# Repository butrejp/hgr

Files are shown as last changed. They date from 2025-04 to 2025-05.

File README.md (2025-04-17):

this is mostly just the kalico config for my 3d printer, eventually including some custom 3d printed parts I've designed for it and some miscellaneous files related to it.  it's mostly here as a backup, but someone may find it useful.

the mainboard is a BTT Octopus Pro v1.1, it uses an nf-crazy volcano uuhf hotend, CPAP fan, 2gt belts on 20t gears, 4mm pitch ball screws for Z, a euclid probe, and mechanical endstops on x and y.  it's a cartesian bed dropper, similar to an ender 5 kinematically

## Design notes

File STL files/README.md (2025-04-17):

the duct is a janky temporary thing, don't use it unless you have to.  I'm working on something more permanent but it's going slow because temporary fixes are forever

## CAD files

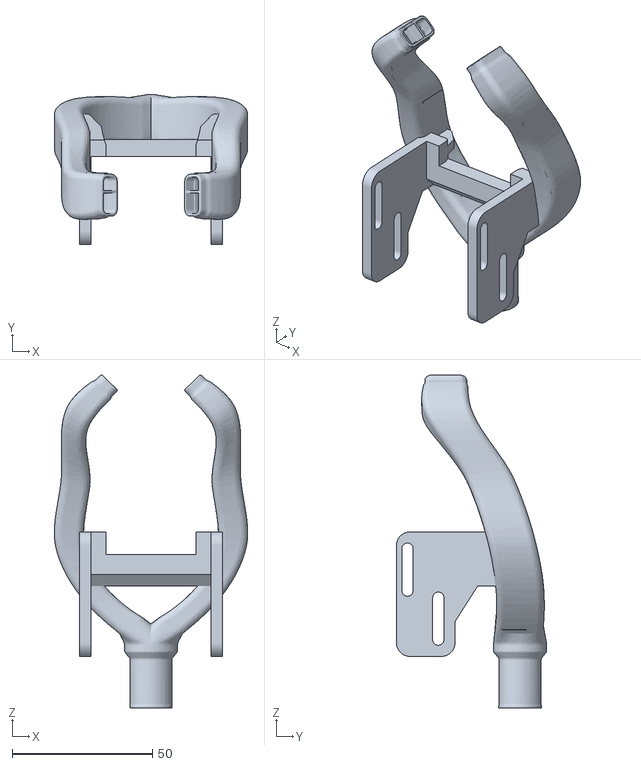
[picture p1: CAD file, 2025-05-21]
STL files/duct final maybe.stl
69.0 x 53.7 x 118.9

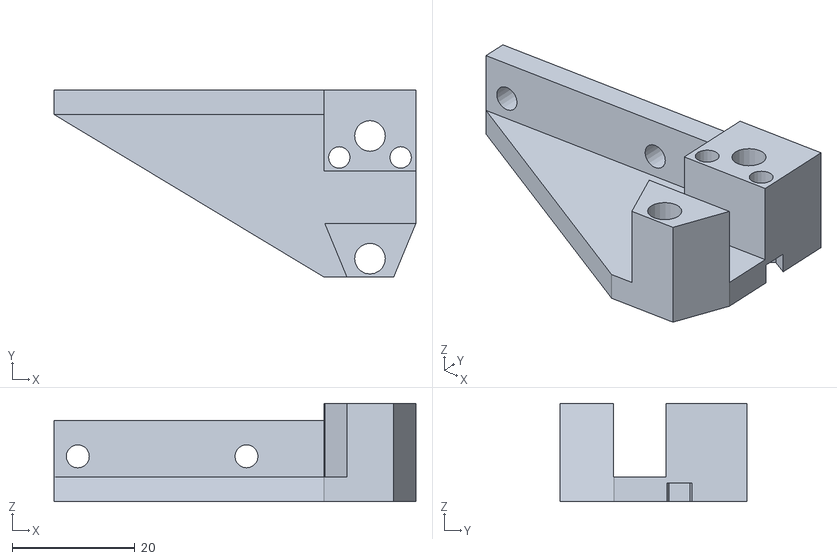
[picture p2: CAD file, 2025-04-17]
STL files/euclid mount.stl
59.0 x 30.5 x 16.0

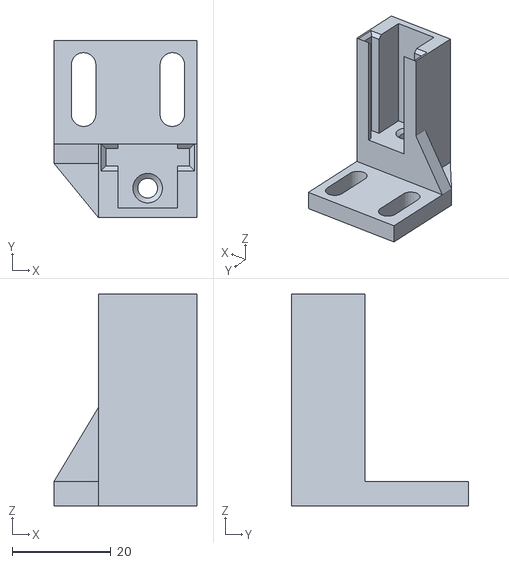
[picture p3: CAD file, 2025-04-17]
STL files/euclid dock.stl
29.0 x 36.0 x 43.0

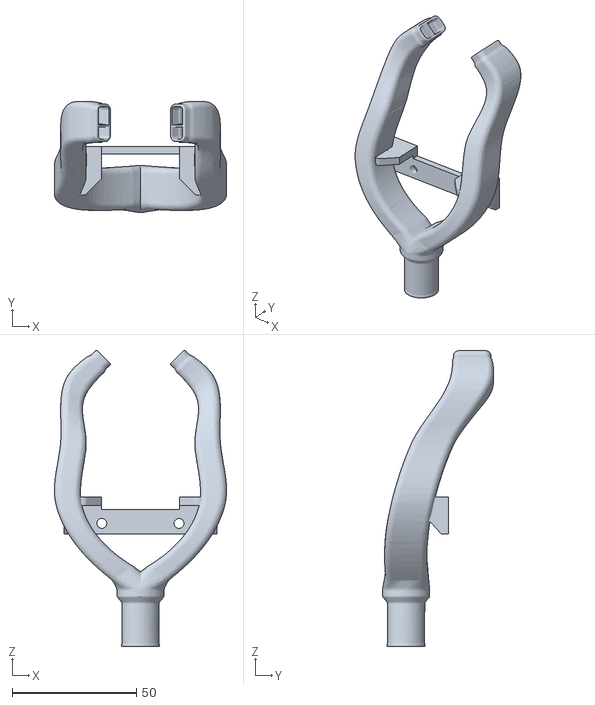
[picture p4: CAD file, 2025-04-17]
STL files/duct_jank.stl
69.1 x 44.6 x 118.9

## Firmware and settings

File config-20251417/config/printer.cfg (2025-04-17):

###########################################################
###       TODO:                                         ###
###       find other things to fix                      ###
###                                                     ###
###########################################################

[include mainsail.cfg]
[include macros.cfg]
[include adxl.cfg]

[mcu]
serial: /dev/serial/by-id/usb-Klipper_stm32h723xx_4A0026000D51313339373836-if00
[gcode_button ESTOP]
pin:PG10
press_gcode:{action_emergency_stop("PULL EMERGENCY STOP SWITCH AND RESTART FIRMWARE")}

[temperature_sensor mcu_temp]
sensor_type: temperature_mcu
min_temp: 0
max_temp: 100
[temperature_sensor electronics_box]
sensor_type:Generic 3950
sensor_pin:PF7
[temperature_sensor chamber_rear]
sensor_type:Generic 3950
sensor_pin:PF6

[printer]
kinematics: cartesian
max_velocity: 600
max_accel: 12000
max_z_velocity: 100
max_z_accel: 75
square_corner_velocity: 20
minimum_cruise_ratio:0

[thermistor dyze500]
temperature1: 25
resistance1: 45000000
temperature2: 260
resistance2: 2240
temperature3: 460
resistance3: 125.4

# Driver0
[extruder]
step_pin: PF13
dir_pin: PF12
enable_pin: !PF14
microsteps: 16
rotation_distance: 8
nozzle_diameter: 0.5
filament_diameter: 1.750
heater_pin: PA0 # HE0
sensor_pin:  PF4 # T0
sensor_type: dyze500
#control: pid
#pid_Kp: 22.2
#pid_Ki: 1.08
#pid_Kd: 114
min_temp: 0
max_temp: 400
min_extrude_temp:0
pressure_advance: 0.015
pressure_advance_smooth_time: 0.01

[tmc5160 extruder]
cs_pin: PC4
spi_bus: spi1
#diag1_pin: PG6
run_current: 0.5
stealthchop_threshold: 0
sense_resistor: 0.075
interpolate: false

# Driver1
[stepper_y]
step_pin: PG0
dir_pin: !PG1
enable_pin: !PF15
microsteps: 16
rotation_distance: 40
endstop_pin: !PG12
position_endstop: 0
position_max: 297
homing_speed: 50

[tmc5160 stepper_y]
cs_pin: PD11
spi_bus: spi1
diag1_pin: PG9
run_current: 2.25
stealthchop_threshold: 0
sense_resistor: 0.075
interpolate: false

# Driver2
[stepper_y1]
step_pin: PF11
dir_pin: !PG3
enable_pin: !PG5
microsteps: 16
rotation_distance: 40

[tmc5160 stepper_y1]
cs_pin: PC6
spi_bus: spi1
#diag1_pin: PG10
run_current: 2.25
stealthchop_threshold: 0
sense_resistor: 0.075
interpolate: false

# Driver3
[stepper_x]
step_pin: PG4
dir_pin: !PC1
enable_pin: !PA2
microsteps: 16
rotation_distance: 40
endstop_pin: !PG6
position_endstop: 0
position_max: 308
homing_speed: 50


[tmc5160 stepper_x]
cs_pin: PC7
spi_bus: spi1
diag1_pin: PG11
run_current: 2
stealthchop_threshold: 0
sense_resistor: 0.075
interpolate: false

# Driver4
[stepper_z]
step_pin: PF9
dir_pin: !PF10
enable_pin: !PG2
microsteps: 16
rotation_distance: 4
endstop_pin: probe:z_virtual_endstop
position_min: -15
position_max: 275

[tmc5160 stepper_z]
cs_pin: PF2
spi_bus: spi1
run_current: 0.800
stealthchop_threshold: 0
sense_resistor: 0.075
interpolate: false

# Driver5
[stepper_z1]
step_pin: PC13
dir_pin: !PF0
enable_pin: !PF1
microsteps: 16
rotation_distance: 4

[tmc5160 stepper_z1]
cs_pin: PE4
spi_bus: spi1
run_current: 0.800
stealthchop_threshold: 0
sense_resistor: 0.075
interpolate: false

[safe_z_home]
home_xy_position:150,150
z_hop:10

[z_tilt]
z_positions:-35,150
            328,150
points:0,105
       270,105
retries: 20
retry_tolerance:0.005
            

[dockable_probe]
dock_position: 307,296
approach_position: 307,260
detach_position: 280,295
pin:PG15
attach_speed:15
detach_speed:15
travel_speed:100
check_open_attach:true
x_offset:27
y_offset:52
#z_offset:0

[bed_mesh]
speed: 150
horizontal_move_z: 5
mesh_min: 27, 52
mesh_max: 290, 290
probe_count: 6, 6

[heater_bed]
heater_pin: PA1
sensor_pin: PF3 # TB
sensor_type: ATC Semitec 104GT-2
#control: watermark
min_temp: 0
max_temp: 130

[multi_pin mcu_fan]
pins: PE5,PD12
[fan_generic mainboard]
pin=multi_pin:mcu_fan
initial_speed: 1

[fan_generic fan0]
pin: PG11
max_power: 0.95 
shutdown_speed: 0 
cycle_time: 0.005
kick_start_time: 0.100 
min_power: 0.1 

[fan_generic fan2]
pin: PA8
min_power: 0.2

[fan_generic fan3] #currently unused, just keeping orca happy.  future chamber exhaust fan
pin: PD14

[led chamber]
white_pin: PD13
cycle_time: 0.01667
hardware_pwm: false
initial_white: 0.5

[gcode_macro M106]
gcode:
    {% set fan = 'fan' + (params.P|int if params.P is defined else 0)|string %}
    {% set speed = (params.S|float / 255 if params.S is defined else 1.0) %}
    SET_FAN_SPEED FAN={fan} SPEED={speed}








# Driver6
#[extruder2]
#step_pin: PE2
#dir_pin: PE3
#enable_pin: !PD4
#heater_pin: PB0 # HE2
#sensor_pin: PF6 # T2
#...

#[tmc5160 extruder2]
#cs_pin: PE1
#spi_bus: spi1
#run_current: 0.800
#stealthchop_threshold: 0

# Driver7
#[extruder3]
#step_pin: PE6
#dir_pin: PA14
#enable_pin: !PE0
#heater_pin: PB11 # HE3
#sensor_pin: PF7 # T3
#...
#[tmc5160 extruder3]
#cs_pin: PD3
#spi_bus: spi1
#run_current: 0.800
#stealthchop_threshold: 0


[board_pins]
aliases:
    # EXP1 header
    EXP1_1=PE8, EXP1_2=PE7,
    EXP1_3=PE9, EXP1_4=PE10,
    EXP1_5=PE12, EXP1_6=PE13,    # Slot in the socket on this side
    EXP1_7=PE14, EXP1_8=PE15,
    EXP1_9=<GND>, EXP1_10=<5V>,

    # EXP2 header
    EXP2_1=PA6, EXP2_2=PA5,
    EXP2_3=PB1, EXP2_4=PA4,
    EXP2_5=PB2, EXP2_6=PA7,      # Slot in the socket on this side
    EXP2_7=PC15, EXP2_8=<RST>,
    EXP2_9=<GND>, EXP2_10=PC5

#*# <---------------------- SAVE_CONFIG ---------------------->
#*# DO NOT EDIT THIS BLOCK OR BELOW. The contents are auto-generated.
#*#
#*# [bed_mesh default]
#*# version = 1
#*# points =
#*# 	  -0.361250, -0.211250, -0.122500, -0.113750, -0.186250, -0.316250
#*# 	  -0.323750, -0.147500, -0.043750, -0.031250, -0.125000, -0.268750
#*# 	  -0.341250, -0.143750, -0.018750, -0.002500, -0.096250, -0.265000
#*# 	  -0.383750, -0.172500, -0.037500, -0.012500, -0.112500, -0.298750
#*# 	  -0.447500, -0.222500, -0.067500, -0.048750, -0.170000, -0.377500
#*# 	  -0.535000, -0.300000, -0.140000, -0.130000, -0.272500, -0.510000
#*# x_count = 6
#*# y_count = 6
#*# mesh_x_pps = 2
#*# mesh_y_pps = 2
#*# algo = lagrange
#*# tension = 0.2
#*# min_x = 27.0
#*# max_x = 290.0
#*# min_y = 52.0
#*# max_y = 290.0
#*#
#*# [dockable_probe]
#*# z_offset = 2.975
#*#
#*# [extruder]
#*# pid_version = 1
#*# pid_target = 250.00
#*# pid_tolerance = 0.0200
#*# control = pid
#*# pid_kp = 20.301
#*# pid_ki = 1.269
#*# pid_kd = 81.206
#*#
#*# [heater_bed]
#*# pid_version = 1
#*# pid_target = 90.00
#*# pid_tolerance = 0.0200
#*# control = pid
#*# pid_kp = 29.242
#*# pid_ki = 0.901
#*# pid_kd = 237.228
#*#
#*# [input_shaper]
#*# shaper_type_x = mzv
#*# shaper_freq_x = 67.8
#*# shaper_type_y = 2hump_ei
#*# shaper_freq_y = 72.6

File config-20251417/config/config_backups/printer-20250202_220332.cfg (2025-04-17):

###########################################################
###                                                     ###
###                                                     ###
###                   TODO:                             ###
###                                                     ###
###       post-config check procedure                   ###
###       get right angle type c adapter (purchased)    ###
###       find other things to fix                      ###
###                                                     ###
###                                                     ###
###########################################################

[include mainsail.cfg]
# Driver0
[extruder]
step_pin: PF13
dir_pin: PF12
enable_pin: !PF14
microsteps: 16
rotation_distance: 7.771
nozzle_diameter: 0.800
filament_diameter: 1.750
heater_pin: PA0 # HE0
sensor_pin:  PF4 # T0
sensor_type: dyze500
control: pid
pid_Kp: 22.2
pid_Ki: 1.08
pid_Kd: 114
min_temp: 0
max_temp: 400
min_extrude_temp:0

[thermistor dyze500]
temperature1: 25
resistance1: 45000000
temperature2: 260
resistance2: 2240
temperature3: 460
resistance3: 125.4

#[filament_switch_sensor material_0]
#switch_pin: PG12


# Driver1
[stepper_y]
step_pin: PG0
dir_pin: !PG1
enable_pin: !PF15
microsteps: 16
rotation_distance: 40
endstop_pin: !PG12
position_endstop: 0
position_max: 296
homing_speed: 50

# Driver2
[stepper_y1]
step_pin: PF11
dir_pin: !PG3
enable_pin: !PG5
microsteps: 16
rotation_distance: 40


# Driver3
[stepper_x]
step_pin: PG4
dir_pin: !PC1
enable_pin: !PA2
microsteps: 16
rotation_distance: 32
endstop_pin: !PG6
position_endstop: 0
position_max: 305
homing_speed: 50


# Driver4
[stepper_z]
step_pin: PF9
dir_pin: !PF10
enable_pin: !PG2
microsteps: 16
rotation_distance: 4
endstop_pin: probe:z_virtual_endstop
position_min: -15
position_max: 200

# Driver5
[stepper_z1]
step_pin: PC13
dir_pin: !PF0
enable_pin: !PF1
microsteps: 16
rotation_distance: 4

[safe_z_home]
home_xy_position:150,150
z_hop:20
[dockable_probe]
dock_position: 305,296
approach_position: 305,260
detach_position: 280,296
pin:PG15
#extract_position: 0,0,0
#insert_position: 0,0,0
#safe_dock_distance :
#safe_position : approach_position
#z_hop: 15.0
#restore_toolhead: True
#dock_retries:
#auto_attach_detach: False
attach_speed:5
detach_speed:5
travel_speed:50
check_open_attach:true
#x_offset:
#y_offset:
z_offset:0
#lift_speed:
#speed:
#samples:
#sample_retract_dist:
#samples_result:
#samples_tolerance:
#samples_tolerance_retries:
#activate_gcode:
#deactivate_gcode:

[bed_mesh]
speed: 150
horizontal_move_z: 5
mesh_min: 0, 0
mesh_max: 270, 250
probe_count: 6, 6



# Driver6
#[extruder2]
#step_pin: PE2
#dir_pin: PE3
#enable_pin: !PD4
#heater_pin: PB0 # HE2
#sensor_pin: PF6 # T2
#...

#[filament_switch_sensor material_2]
#switch_pin: PG14

# Driver7
#[extruder3]
#step_pin: PE6
#dir_pin: PA14
#enable_pin: !PE0
#heater_pin: PB11 # HE3
#sensor_pin: PF7 # T3
#...


[heater_bed]
heater_pin: PA1
sensor_pin: PF3 # TB
sensor_type: ATC Semitec 104GT-2
control: watermark
min_temp: 0
max_temp: 130

[multi_pin mcu_fan]
pins: PE5,PD12
[fan_generic mainboard]
pin=multi_pin:mcu_fan
initial_speed: 1

[fan_generic aux]
pin: PA8
min_power: 0.2

[fan]
pin: PG11
max_power: 0.95 
shutdown_speed: 0 
cycle_time: 0.005
kick_start_time: 0.100 
min_power: 0.1 



[mcu]
serial: /dev/serial/by-id/usb-Klipper_stm32h723xx_4A0026000D51313339373836-if00


[printer]
kinematics: cartesian
max_velocity: 700
max_accel: 10000
max_z_velocity: 5
max_z_accel: 100


######################
## FIX THIS SECTION ##
######################

#driver0
[tmc5160 extruder]
cs_pin: PC4
spi_bus: spi1
#diag1_pin: PG6
run_current: 0.800
stealthchop_threshold: 0
sense_resistor: 0.075

#driver1
[tmc5160 stepper_y]
cs_pin: PD11
spi_bus: spi1
diag1_pin: PG9
run_current: 2
stealthchop_threshold: 0
sense_resistor: 0.075

#driver2
[tmc5160 stepper_y1]
cs_pin: PC6
spi_bus: spi1
#diag1_pin: PG10
run_current: 2
stealthchop_threshold: 0
sense_resistor: 0.075

#driver3
[tmc5160 stepper_x]
cs_pin: PC7
spi_bus: spi1
diag1_pin: PG11
run_current: 2
stealthchop_threshold: 0
sense_resistor: 0.075

#driver4
[tmc5160 stepper_z]
cs_pin: PF2
spi_bus: spi1
run_current: 0.800
stealthchop_threshold: 0
sense_resistor: 0.075

#driver5
[tmc5160 stepper_z1]
cs_pin: PE4
spi_bus: spi1
run_current: 0.800
stealthchop_threshold: 0
sense_resistor: 0.075

#driver6
#[tmc5160 extruder2]
#cs_pin: PE1
#spi_bus: spi1
#run_current: 0.800
#stealthchop_threshold: 0

#driver7
#[tmc5160 extruder3]
#cs_pin: PD3
#spi_bus: spi1
#run_current: 0.800
#stealthchop_threshold: 0

[board_pins]
aliases:
    # EXP1 header
    EXP1_1=PE8, EXP1_2=PE7,
    EXP1_3=PE9, EXP1_4=PE10,
    EXP1_5=PE12, EXP1_6=PE13,    # Slot in the socket on this side
    EXP1_7=PE14, EXP1_8=PE15,
    EXP1_9=<GND>, EXP1_10=<5V>,

    # EXP2 header
    EXP2_1=PA6, EXP2_2=PA5,
    EXP2_3=PB1, EXP2_4=PA4,
    EXP2_5=PB2, EXP2_6=PA7,      # Slot in the socket on this side
    EXP2_7=PC15, EXP2_8=<RST>,
    EXP2_9=<GND>, EXP2_10=PC5

# See the sample-lcd.cfg file for definitions of common LCD displays.

# A [probe] section can be defined instead with a pin: setting identical
# to the sensor_pin: for a bltouch
#[bltouch]
#sensor_pin: PB7
#control_pin: PB6
#z_offset: 0

#[neopixel my_neopixel]
#pin: PB10
